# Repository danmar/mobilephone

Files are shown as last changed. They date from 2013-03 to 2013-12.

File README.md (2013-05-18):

# mobilephone

Project to build a simple mobile phone (GSM). The mobile phone will handle
voice calls.

I will use off-the-shelf electronic components.

The software development and electronic components is sponsored by
Evidente.

## Progress

### Step 1 : GSM chip

I bought a SM5100B GSM chip, a simple evaluation board for this chip, and a
GSM antenna. The chip understands AT commands.

I bought a normal prepaid comviq sim card.

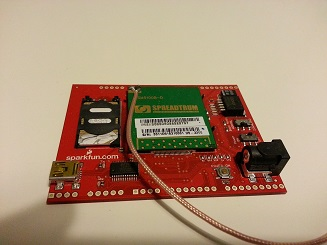
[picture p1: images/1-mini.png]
Chip


### Step 2 : Setup

I connected everything and tried to setup the chip for the GSM card. It was
quite straight forward.

By using AT commands from my PC I can send/receive SMS and dial/answer voice
calls (however I have no audio yet).

### Step 3 : Audio

The plan in this "step" is to connect a microphone and speaker. The datasheet
for SM5100B has reference designs for connecting microphone and speaker that
I will try to use.

According to the datasheet, the speaker can be connected directly to output
pins on the chip.

Before I had any parts, I wanted to "dry run" the audio. When a voice call is
made, it should be possible to measure something on the speaker output. I made
this connection:
  GSM chip speaker output => voltage divider => microphone input on my PC

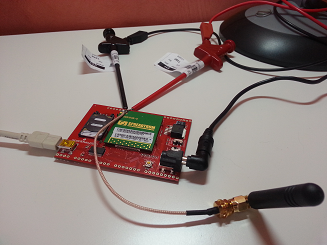
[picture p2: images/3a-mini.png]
Connection


Oscilloscope view when I whizzle in the calling telephone

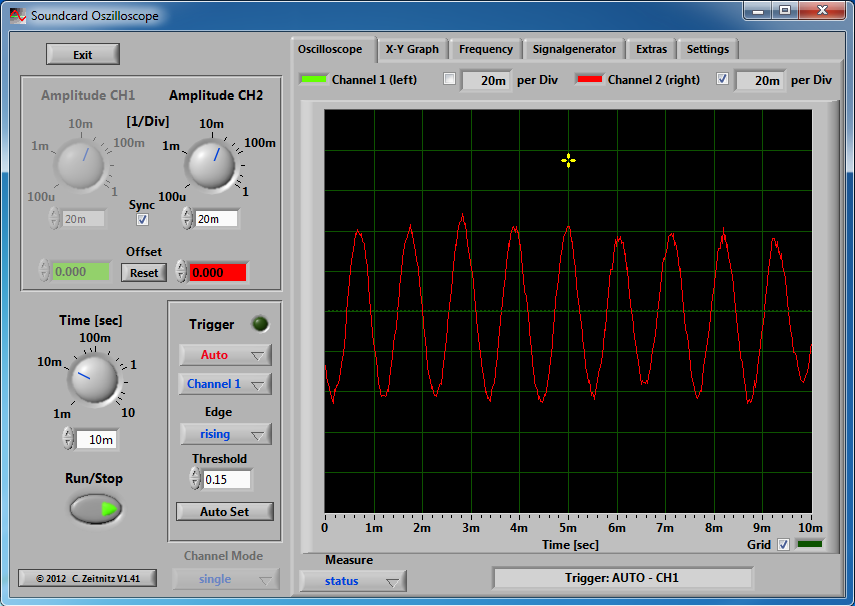
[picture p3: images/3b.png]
Oscilloscope view


Audio recording when I say "test, test". It's very faint.

http://github.com/danmar/mobilephone/raw/master/images/3.wma

### Step 4 : Connecting the microcontroller to the GSM chip

Here I have connected a MBED microcontroller to the UART0 port on the GSM chip:

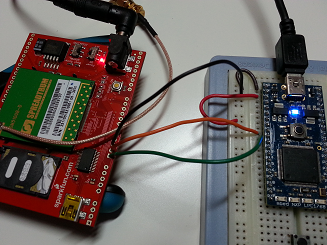
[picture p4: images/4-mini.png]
MBED


To start with the MBED just sends "AT" commands and then receive the response "OK".

### Step 5 : Prototype box

I bought a small box. The microphone and speaker I bought was connected. The
reference circuits from the datasheets worked fine!

Internal view:

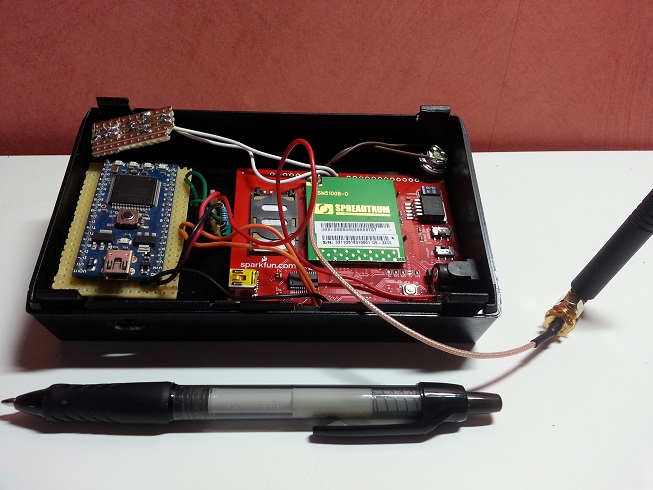
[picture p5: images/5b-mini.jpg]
Internal


External view:

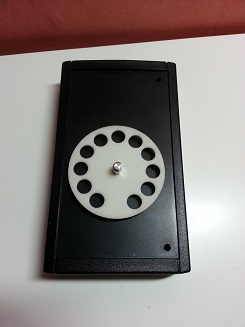
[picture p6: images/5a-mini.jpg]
External


The dialer is both used to dial numbers and to answer / hang up. By spinning the dialer
all the way twice you answer and hang up.

It works when using a AC/DC power adaptor. But unfortunately it doesn't work well from a
battery. I use a normal 9V battery right now. This may be too weak.

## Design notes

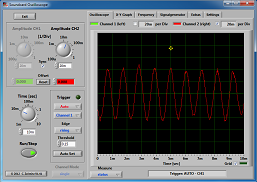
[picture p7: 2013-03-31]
images/3b-mini.png

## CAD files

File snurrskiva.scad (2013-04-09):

module snurrskiva(diameter,height)
{
	radius = diameter / 2;

	difference() {
		cylinder(h = height, r = radius, center = true, $fn=100);

		for (i = [0:9]) {
			translate([0.75*radius*sin(i*30),0.75*radius*cos(i*30),0]) {
				cylinder(h=2*height, r=0.15*radius, center=true, $fn=100);
				cylinder(h=2*height, r1=0, r2=0.25*radius, center=true, $fn=100);
				cylinder(h=2*height, r1=0.25*radius, r2=0, center=true, $fn=100);
			}
		}
	}
}

snurrskiva(60,2);

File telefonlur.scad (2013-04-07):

module roundedcylinder(radius, height, r2) {
    cylinder(h=height, r=radius);
    translate([0, 0, -r2])
        cylinder(h=r2, r=radius-r2);
    for (i=[0:359]) {
        translate([(radius-r2)*sin(i), (radius-r2)*cos(i), 0])
            sphere(r2);
    }
}

module roundedcube(x,y,z,r2) {
    cube([x, y, z]);
    translate([0,r2,-r2])
        cube([x,y-2*r2,r2]);
    translate([0,r2,0])
        rotate(90, [0,1,0]) cylinder(r=r2,h=x);
    translate([0,y-r2,0])
        rotate(90, [0,1,0]) cylinder(r=r2,h=x);
}

module telefonlur(length, width, height1, height2)
{
    roundedcube(length, width, height1, width/10);

    translate([0,width/2,0]) {
        roundedcylinder(width/2, height2, width/10);
    }

    translate([length,width/2,0]) {
        roundedcylinder(width/2, height2, width/10);
    }
}

telefonlur(120, 50, 5, 20);

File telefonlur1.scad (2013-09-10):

// Draw simple empty box with 2mm thickness
module drawbox(x,y,z) {
    difference() {
        cube([x+4, y+4, z]);
        translate([2,2,2]) {
            cube([x, y, z]);
        }
    }
}

// Draw two bars that holds potentiometer in place
module potholder() {
        translate([-7,-5,0]) {
            cube([2,10,5]);
        }
        translate([5,-5,0]) {
            cube([2,10,5]);
        }
}

// Draw box
module drawbox2(x,y,z,yoffset) {
    difference() {
        drawbox(x,y,z);
        translate([x/2,yoffset,1]) {
            cylinder(h=4,r=2,center=true, $fn=100);
        }
    }
    translate([x/2,yoffset,0]) {
        potholder();
    }
}

module drawmbed() {
    cube([65,35,10]);
}

module drawgsm() {
    cube([65,85,5]);
}

translate([-35,-50,-5]) {
    drawbox2(70,145,10,50);
}

translate([-30,-45,5]) {
    drawmbed();
}
translate([-30,10,5]) {
    drawgsm();
}

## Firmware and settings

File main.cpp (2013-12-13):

#include "mbed.h"

Serial ser(p9,p10); // tx,rx
Serial pc(USBTX, USBRX); // tx, rx

DigitalOut led1(LED1);
DigitalOut led2(LED2);
DigitalOut led3(LED3);
DigitalOut led4(LED4);

PwmOut buzzer(p23);

static int readADC(int pin);

static int getDialRawValue()
{
    int x = 1000 * readADC(19) / readADC(20);
    if (x > 1000)
        x = 1000;
    return 1000 - x;
}

void restart()
{
    const char cmd[] = "AT+CFUN=1,1\r\n";
    ser.printf(cmd);
    pc.printf(cmd);
}

void answer()
{
    const char cmd[] = "ATA\r\n";
    ser.printf(cmd);
    pc.printf(cmd);
}

const char *receivedMessage;
int byteReceived;

void startPhone()
{
    int sind = 0;

    while (true) {
        restart();
        for (int counter = 0; sind != 11 && counter < 600; counter++) {
            wait_ms(100);
            led1 = ((counter & 3) == 0);
            led2 = ((counter & 3) == 1);
            led3 = ((counter & 3) == 2);
            led4 = ((counter & 3) == 3);

            if (receivedMessage) {
                char buf[100];
                strcpy(buf, receivedMessage);
                receivedMessage = NULL;

                pc.printf("%s\r\n", buf);

                if (strncmp(buf,"+SIND:",6) == 0)
                    pc.printf(" => SIND=%i\r\n", sind = atoi(buf+6));
            }
        }
        if (sind == 11)
            break;

        pc.printf("Failed to login");
        buzzer = 0.5;
        wait(1);
        buzzer = 0;
    }

    for (int i = 0; i < 10; i++) {
        buzzer = (i & 1) * 0.5;
        wait_ms(100);
    }

    led1 = 0;
    led2 = 0;
    led3 = 0;
    led4 = 0;

    buzzer = 0;
}

void phone()
{
    int counter = 0;
    int ringcounter = 0;
    int ringcounter2 = 0;
    int ringcode = 0;

    enum { WAIT, DIAL, TALK } status = WAIT;

    startPhone();

    while (1) {
        wait_ms(100);

        counter++;
        led1 = ((counter >> 2) & 1);

        if (ringcounter > 0) {
            --ringcounter;
            led1 = ringcounter & 1;
            led2 = ringcounter & 1;
            led3 = ringcounter & 1;
            led4 = ringcounter & 1;
            buzzer = (ringcounter & 1) * 0.5;
        }

        if (ringcounter2 > 0)
            --ringcounter2;
        else
            ringcode = 0;

        // Dial number..
        if (status == WAIT && ringcounter2 == 0) {
            static int maxDialRawValue = 0;
            const int dialRawValue = getDialRawValue();
            if (dialRawValue > maxDialRawValue)
                maxDialRawValue = dialRawValue;
            if (dialRawValue == 0 && maxDialRawValue > 20) {
                static const int rawValue[] = { 30, 155, 252, 390, 500, 620, 750, 860, 970, 1000 };
                int num = (maxDialRawValue == 1000) ? 9 : 0;
                while (maxDialRawValue > rawValue[num] + 40)
                    num++;
                if (maxDialRawValue < rawValue[num] - 40) {
                    pc.printf("nr: %i\r\n", maxDialRawValue);
                    maxDialRawValue = 0;
                    continue;
                }
                pc.printf("nr: %i %i ", num, maxDialRawValue);
                maxDialRawValue = 0;

                static char dialnumber[32];
                int i = 0;
                while (i < 30 && dialnumber[i] != '\0')
                    i++;
                dialnumber[i] = '0' + num;

                if (i >= 2 && strcmp(dialnumber+i-2, "999") == 0)
                    memset(dialnumber, 0, sizeof(dialnumber));

                if (i == 0 && num != 0)
                    memset(dialnumber, 0, sizeof(dialnumber));

                pc.printf("dialnr=%s\r\n", dialnumber);

                if (strcmp(dialnumber,"055")==0) {
                    const char cmd[] = "ATD0709124262\r\n";
                    ser.printf(cmd);
                    pc.printf(cmd);
                    memset(dialnumber, 0, sizeof(dialnumber));
                }

                if (dialnumber[9] != '\0') {
                    if (strcmp(dialnumber, "0709124262") == 0 || strcmp(dialnumber, "0736156826") == 0) {
                        status = DIAL;
                        char cmd[32];
                        strcpy(cmd, "ATD");
                        strcat(cmd, dialnumber);
                        strcat(cmd, "\r\n");
                        ser.printf(cmd);
                        pc.printf(cmd);
                    }
                    memset(dialnumber, 0, sizeof(dialnumber));
                }
            }
        }

        // Answer..
        if (status == WAIT && ringcounter > 0) {
            const int dialRawValue = getDialRawValue();
            if (dialRawValue < 50)
                ringcode |= 1;
            else if (dialRawValue > 950)
                ringcode |= 2;
            if (ringcode == 3) {
                answer();
                ringcounter = ringcounter2 = 0;
                status = TALK;

                led1 = true;
                led2 = true;
                led3 = true;
                led4 = true;

                buzzer = 0;
            }
        }

        // Hang up
        {
            static int hangUpCode;
            static int hangUpCounter;

            if (status == TALK || status == DIAL) {
                if (hangUpCounter > 0)
                    hangUpCounter--;
                else
                    hangUpCode = 0;

                const int dialRawValue = getDialRawValue();
                int num = 0;
                if (dialRawValue < 50)
                    num = 1;
                else if (dialRawValue > 950)
                    num = 2;
                if ((num != hangUpCode) && (num == 1 || num == 2)) {
                    if (hangUpCode != 0) {
                        led1 = false;
                        led2 = false;
                        led3 = false;
                        led4 = false;
                        status = WAIT;
                        ser.printf("ATH\r\n");
                        pc.printf("ATH\r\n");
                    } else {
                        hangUpCode = num;
                        hangUpCounter = 20;
                    }
                }
            }

            if (status == WAIT)
                hangUpCode = hangUpCounter = 0;
        }

        // Read from GSM
        while (receivedMessage != NULL) {
            char buf[100];
            strcpy(buf, receivedMessage);
            receivedMessage = NULL;

            pc.printf("%s\r\n", buf);

            if (strcmp(buf, "RING") == 0) {
                ringcounter = 40;
                ringcounter2 = 60;
            }

            if (strncmp(buf, "NO CARRIER", 10) == 0) {
                led1 = false;
                led2 = false;
                led3 = false;
                led4 = false;
                status = WAIT;
                pc.printf("HANGUP!\r\n");
            }
        }
    }
}

void receivebyte()
{
    static char buffer[100];
    static int bufindex = 0;

    char c = ser.getc();

    if (receivedMessage == NULL) {
        if (c == '\r' || c == '\n') {
            if (bufindex > 0)
                receivedMessage = buffer;
            buffer[bufindex] = 0;
            bufindex = 0;
        }

        else if (bufindex < sizeof(buffer)-1)
            buffer[bufindex++] = c;
    }

    byteReceived = 2;
}

static void initADC(int pins)
{
    NVIC_DisableIRQ(ADC_IRQn);

    // Power on the ADC
    LPC_SC->PCONP |= 1 << 12;

    // PCLK = 96MHz / 4 = 12MHz
    LPC_SC->PCLKSEL0 &= ~(3 << 24);

    unsigned int mask = 0;
    if (pins & (1<<19)) // P19 = AD0.4
        mask |= 3UL << 28;
    if (pins & (1<<20)) // P20 = AD0.5
        mask |= 3UL << 30;
    LPC_PINCON->PINSEL3 |= mask;

    LPC_ADC->ADCR = (1 << 8)     // CLKDIV=1
                    | (1 << 21);   // PDN
}

static int readADC(int pin)
{
    static const unsigned int AD_CR_START_MASK = 7 << 24;
    static const unsigned int AD_CR_START_NOW  = 1 << 24;
    static const unsigned int AD_CR_SELMASK    = 0xff;
    static const unsigned int AD_DR_DONE       = 1UL << 31;

    if (pin < 15 || pin > 20)
        return 0;

    // Stop ADC
    LPC_ADC->ADCR &= ~(AD_CR_START_MASK | AD_CR_SELMASK);

    // Start conversion
    LPC_ADC->ADCR |= (AD_CR_START_NOW | (1 << (pin-15)));

    // Wait for conversion done
    while ((LPC_ADC->ADGDR & AD_DR_DONE) == 0)
        ;

    // Return result
    return ((LPC_ADC->ADGDR >> 4) & 0xfff);
}

void testaSnurrskivan()
{
    int count = 0;

    pc.printf("testa snurrskivan\r\n");
    while (true) {
        wait_ms(100);

        if (byteReceived == 0) {
            pc.printf("%i\n", getDialRawValue());
        } else {
            byteReceived--;
        }

        led1 = (byteReceived > 0);
        if (byteReceived)
            byteReceived--;

        count = (count + 1) & 31;
        if (count == 0)
            ser.printf("AT\r");
    }
}

int main()
{
    ser.baud(115200);
    pc.baud(115200);

    pc.printf("START!\r\n");

    buzzer.period_us(250);
    buzzer = 0;

    ser.attach(&receivebyte);

    initADC((1<<19) | (1<<20));

    phone();

    return 0;
}

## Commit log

2013-03-31 added 3.wma. Recorded by connecting: speaker output => voltage divider => microphone input on PC
2013-04-01 added uart image
2013-04-04 snurrskiva: added scad file
    [snurrskiva.scad]
2013-04-07 Added 'telefonlur.scad'. First simple design.
    [telefonlur.scad]
2013-04-08 Call my phone when I press button
2013-04-09 added parameters and increased resolution for snurrskiva
    [snurrskiva.scad]
2013-04-09 snurrskiva: 10 holes
    [snurrskiva.scad]
2013-04-18 better initialization of phone. answer calls with button
2013-04-26 sw: broke up main function into subfunctions. refactored the rx handling. started work on analog input, the AnalogIn class didn't work very well. This code probably doesn't work as good as the previo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
    [main.cpp]
2013-05-04 Better handling of finger plate. Read voltage from both p19 and p20. hangup. dial (only '5'). answer call.
2013-09-10 Draw new box for electronics
    [telefonlur1.scad]
2013-09-10 Add components to electronics box
    [telefonlur1.scad]
2013-12-13 tell that phone is registered on network with buzzer
    [main.cpp]
